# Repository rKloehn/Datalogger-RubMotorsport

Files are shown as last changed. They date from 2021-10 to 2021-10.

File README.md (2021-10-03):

# Datalogger-RubMotorsport

## Overview

For all RUB-Motorsport vehicles it makes sense to install a data logger in the vehicle. This can access and log all engine data (from the MS3) and all sensor data via the CAN bus. Up to now, RUBMotorsport has used a purchased data logger from 2D. This works well and has worked reliably over the years. However, only one data logger is available, due to the very high purchase price and the relatively easy installation in new vehicles, a new purchase was not made. The big disadvantage of this data logger is the software that comes with it. This must be used to export data from the data logger in e.g. *.csv files. The software license must be renewed every year, at the latest in February for one year. For the renewal of the license there is an annual fee of 500€. Due to the reasons mentioned above, in the 2020 season we will develop our own data logger based on a STM32F405RG. This should have all the previous functions of the 2D data logger and at a later date can also be integrated into the planned telemetry concept. 

The data logger has several connections to the outside world. These include the power supply of 12V, the connection to a GPS antenna, the possibility to process four sensor analog signals and supply them with voltage and the measurement of acceleration using an IMU. The option to store the measurement data on a microSD card is also part of the peripherals.

<p align="center">
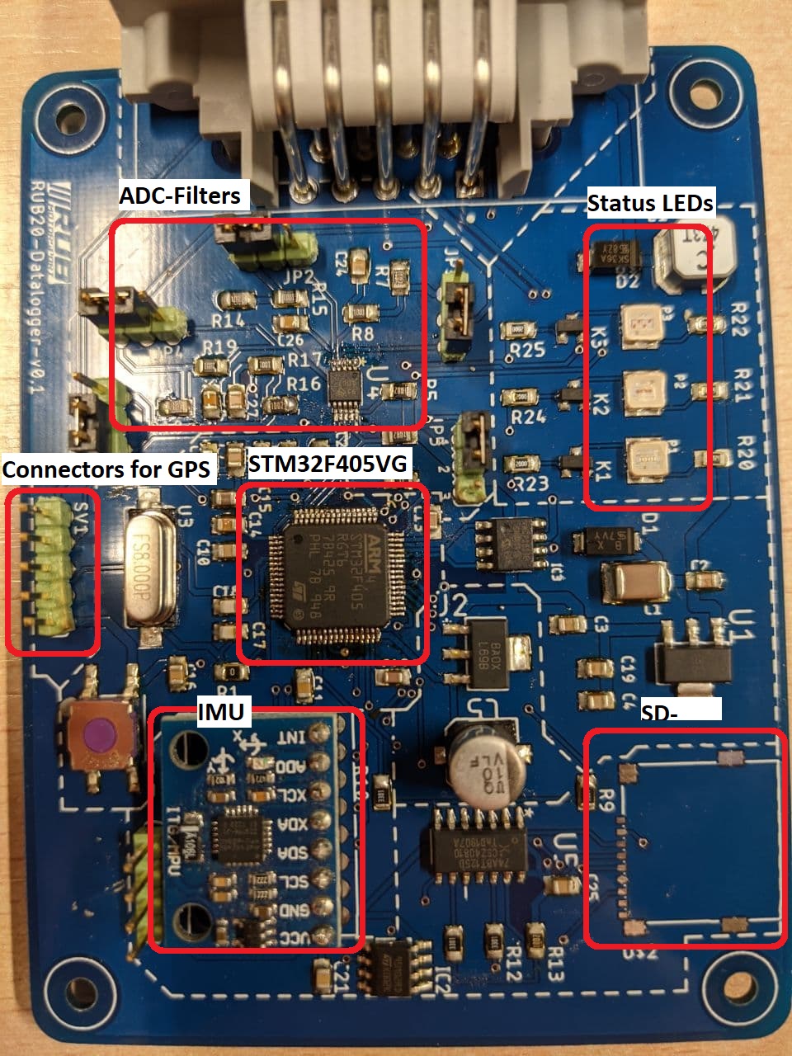
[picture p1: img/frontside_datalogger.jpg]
	
</p>

<p align="center">
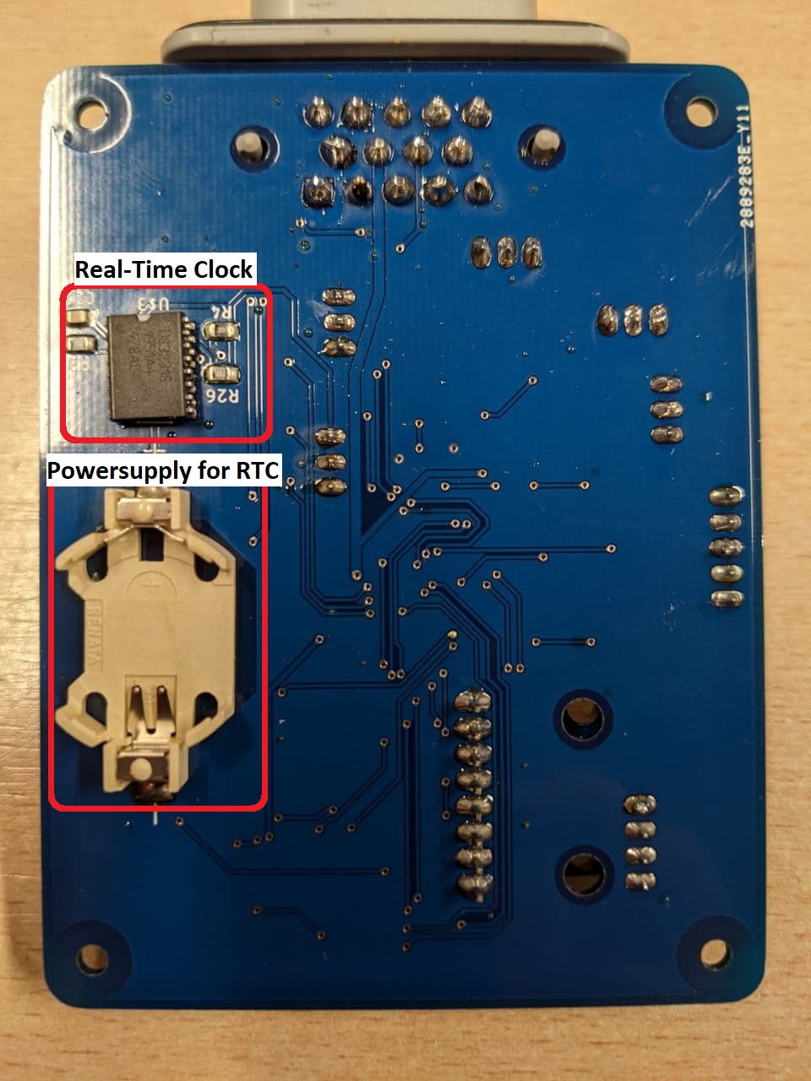
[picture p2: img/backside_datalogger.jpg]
	
</p>

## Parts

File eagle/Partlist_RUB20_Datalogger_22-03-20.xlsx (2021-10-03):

Part | Value | Package | Library | Bestellnummer
C1 | 22u | C1812K | rcl
C2 | 0.33u | C0805 | rcl
C3 | 0.1u | C0805 | rcl
C4 | 0.1u | C0805 | rcl
C5 | 10UF | CAPAE430X610N | Panasonic-EEEFK_EEEFP
C6 | 4.7u | C0805 | rcl
C7 | 0.1u | C0805 | rcl
C8 | 0.1u | C0805 | rcl
C9 | 0.1 | C0805 | rcl
C10 | 0.1 | C0805 | rcl
C11 | 0.1 | C0805 | rcl
C12 | 2.2u | C0805 | rcl
C13 | 2.2u | C0805 | rcl
C14 | 10n | C0805 | rcl
C15 | 1u | C0805 | rcl
C16 | 0.1u | C0805 | rcl
C17 | 20p | C0805 | rcl
C18 | 20p | C0805 | rcl
C19 | 0.1u | C0805 | rcl
C20 | 0.1u | C0805 | rcl
C21 | 100n | C0805 | rcl
C24 | 1n | C0805 | rcl
C25 | 100n | C0805 | rcl
C26 | 1n | C0805 | rcl
C27 | 1n | C0805 | rcl
C28 | 1n | C0805 | rcl
D1 | SMAJ22 | SMA-DO214AC | RUBM_PARTS
D2 | SK36SMA | DO214AC | RUBM_PARTS
IC1 | STM32F405RG | LQFP64 | RUBM_PARTS
IC2 | M95M02-DRMN6TP | SOIC127P600X175-8N | SamacSys_Parts
IC3 | MCP2551 | 8SO | RUBM_PARTS
JP1 | 1X03 | pinhead | (1050
JP2 | 1X03 | pinhead | (776.79995
JP3 | 1X03 | pinhead | (1405
JP4 | 1X03 | pinhead | (1050
JP5 | JP2 | jumper | (1600
K1 | IRLML62244 | SOT23-MICRO | RUBM_PARTS
K2 | IRLML62244 | SOT23-MICRO | RUBM_PARTS
K3 | IRLML62244 | SOT23-MICRO | RUBM_PARTS
L1 | LPS6235 | LPS6235 | RUBM_PARTS
P1 | XLAMP_ML-E | CREE_XLAMP_ML-E | RUBM_PARTS
P2 | XLAMP_ML-E | CREE_XLAMP_ML-E | RUBM_PARTS
P3 | XLAMP_ML-E | CREE_XLAMP_ML-E | RUBM_PARTS
R1 | 0 | R0805 | rcl
R2 | 0 | R0805 | rcl
R5 | 10k | R0805 | rcl
R6 | 10k | R0805 | rcl
R7 | 10k | R0805 | rcl
R8 | 1k | R0805 | rcl
R9 | 3.3k | R0805 | rcl
R10 | 3.3k | R0805 | rcl
R11 | 3.3k | R0805 | rcl
R12 | 3.3k | R0805 | rcl
R13 | 10k | R0805 | rcl
R14 | 10k | R0805 | rcl
R15 | 1k | R0805 | rcl
R16 | 10k | R0805 | rcl
R17 | 1k | R0805 | rcl
R18 | 10k | R0805 | rcl
R19 | 1k | R0805 | rcl
R20 | 48.7 | R0805 | rcl
R21 | 48.7 | R0805 | rcl
R22 | 48.7 | R0805 | rcl
R23 | 200 | R0805 | rcl
R24 | 200 | R0805 | rcl
R25 | 200 | R0805 | rcl
S1 | KSE-M-31-G | KSE-M-31-G | RUBM_PARTS
SV1 | 1X05 | pinhead | (1950
SV2 | 1X04 | pinhead | (3100
U$1 | 776267-4 | TE_776267-4 | 776267-4
U$2 | MICROSD-PUSH-OUT | MICROSD-PUSH-OUT | microsd
U1 | UA78M05CDCY | SOT230P700X180-4N | RUBM_PARTS
U2 | LM2937IMP-3.3/NOPB | SOT230P700X180-4N | RUBM_PARTS
U3 | FOX_SDLF | HC49SSDLF | RUBM_PARTS
U4 | ADS1115IDGST | SOP50P490X110-10N | Texas |  | R0
U5 | 74ABT125D | SOIC127P600X175-14N | NXP_By_element14_Batch_1
U6 | GY-521MPU6050 | GY-521 | gy-521_holes

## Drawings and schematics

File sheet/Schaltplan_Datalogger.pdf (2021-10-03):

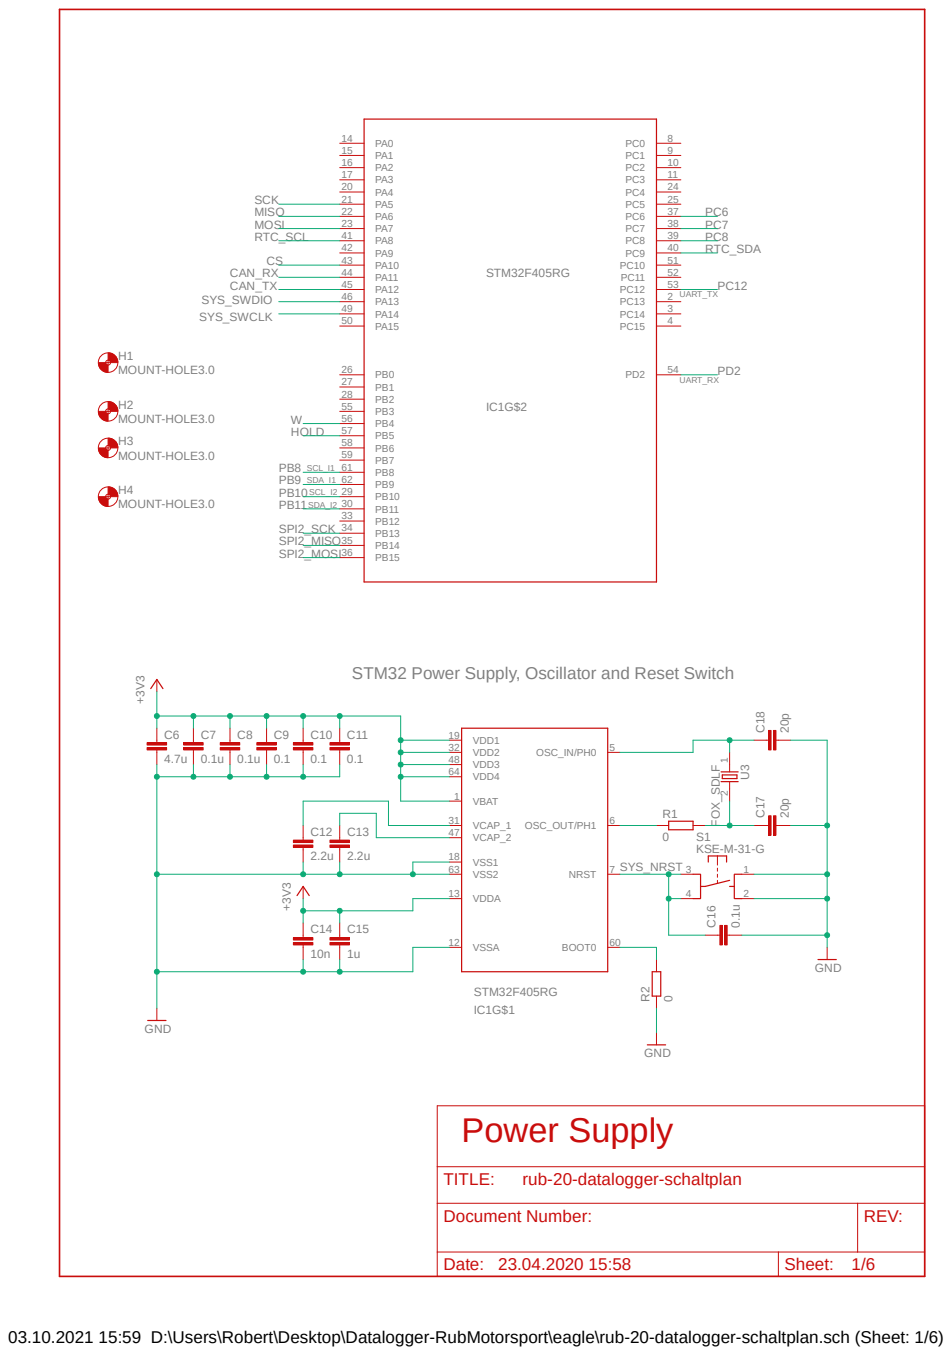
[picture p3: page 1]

STM32 Power Supply, Oscillator and Reset Switch

Document Number: | REV:

Date: 23.04.2020 15:58 | Sheet: 1/6

03.10.2021 15:59 D:\Users\Robert\Desktop\Datalogger-RubMotorsport\eagle\rub-20-datalogger-schaltplan.sch (Sheet: 1/6)

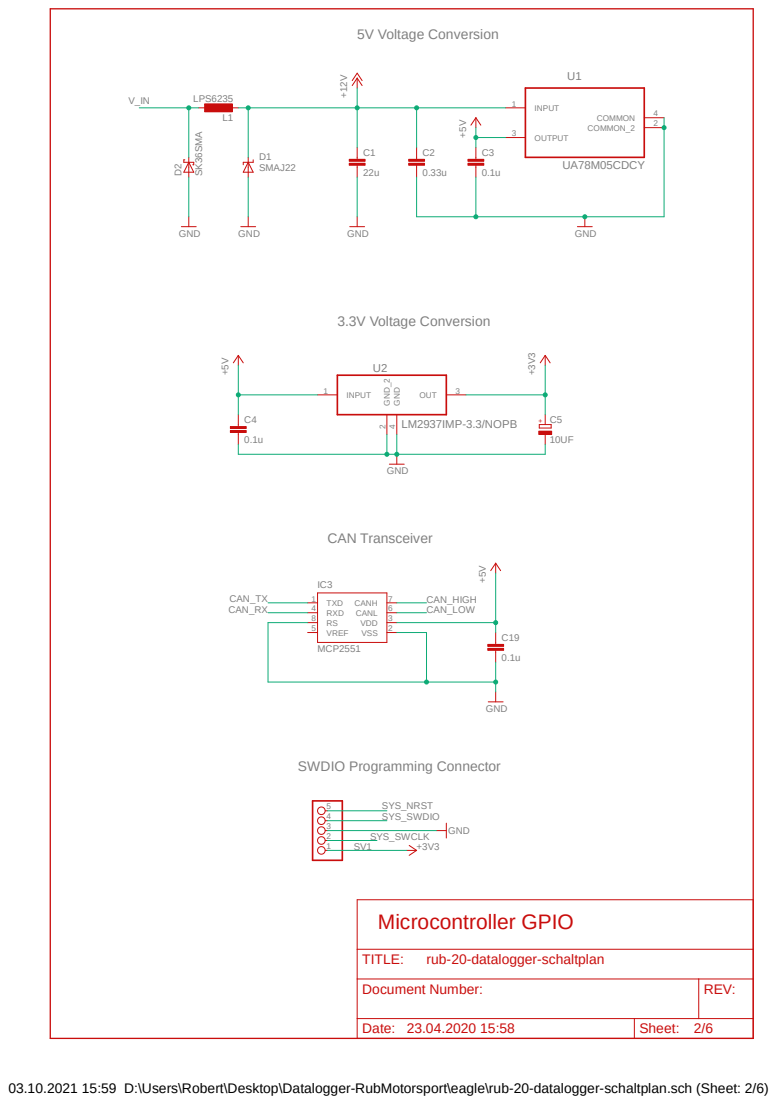
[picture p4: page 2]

Document Number: | REV:

03.10.2021 15:59 D:\Users\Robert\Desktop\Datalogger-RubMotorsport\eagle\rub-20-datalogger-schaltplan.sch (Sheet: 2/6)

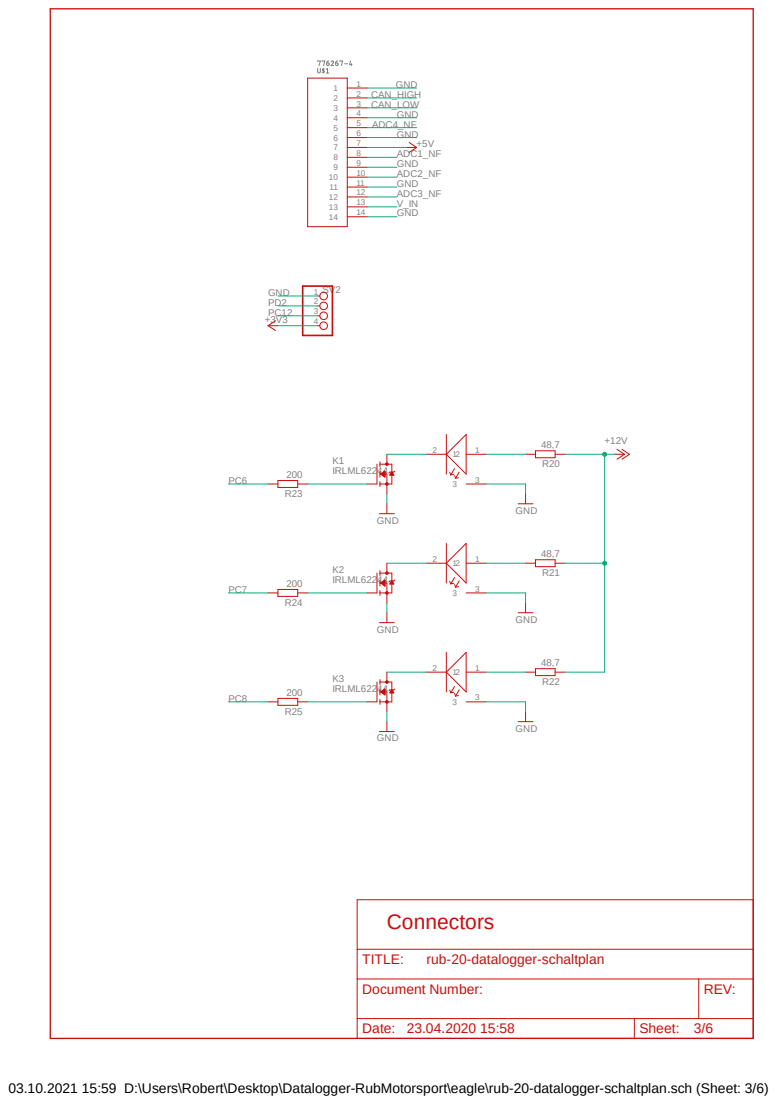
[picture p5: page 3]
GND; IRLML62244; CAN_HIGH CAN_LOW; ADC1_NF; ADC2_NF; ADC3_NF; ADC4_NF; Connectors; TITLE:

rub-20-datalogger-schaltplan

Document Number: | REV:

03.10.2021 15:59 D:\Users\Robert\Desktop\Datalogger-RubMotorsport\eagle\rub-20-datalogger-schaltplan.sch (Sheet: 3/6)

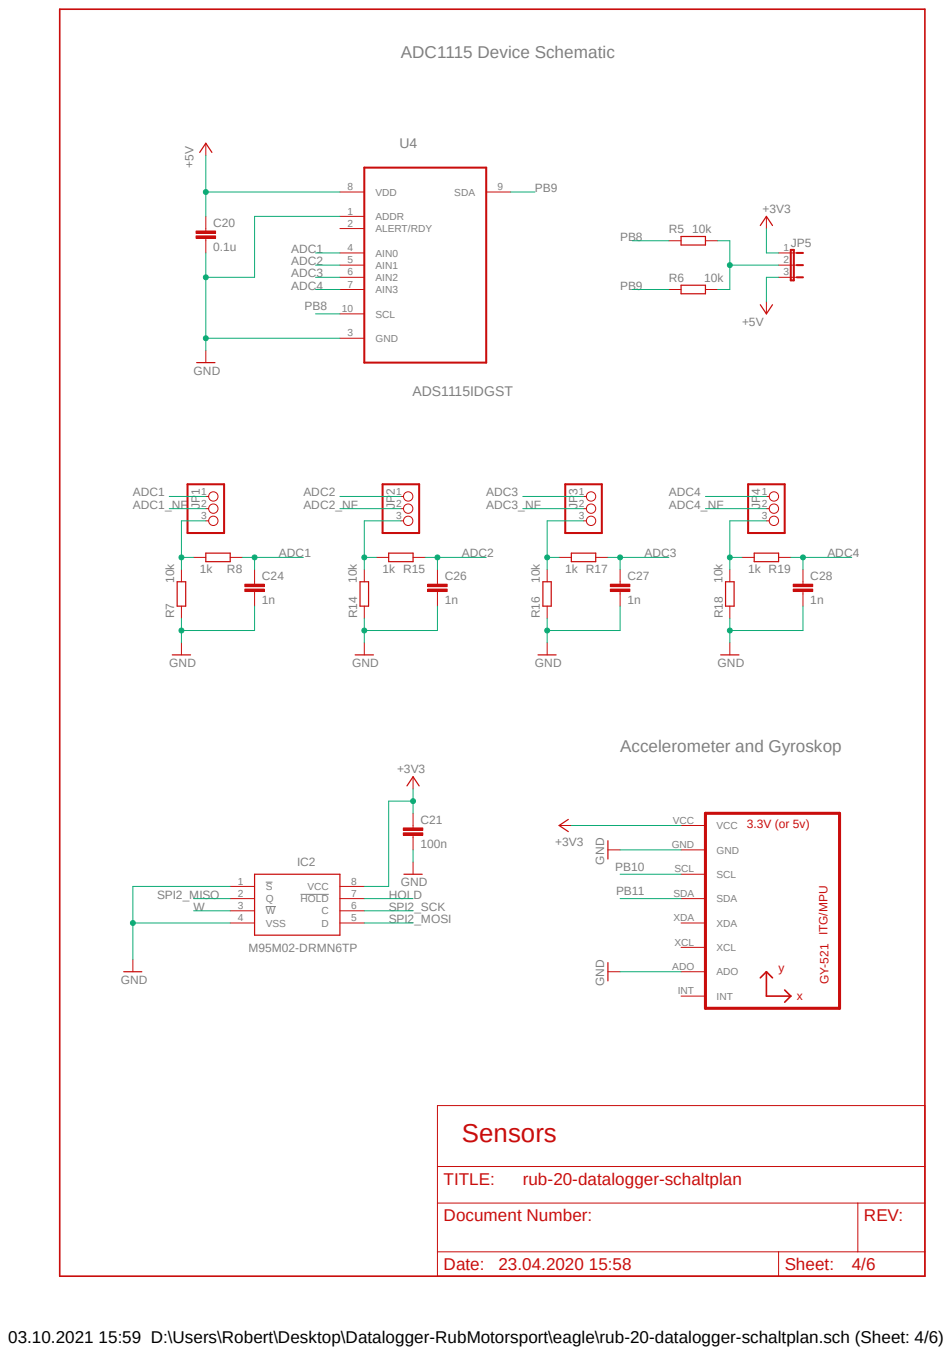
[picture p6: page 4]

Document Number: | REV:

03.10.2021 15:59 D:\Users\Robert\Desktop\Datalogger-RubMotorsport\eagle\rub-20-datalogger-schaltplan.sch (Sheet: 4/6)

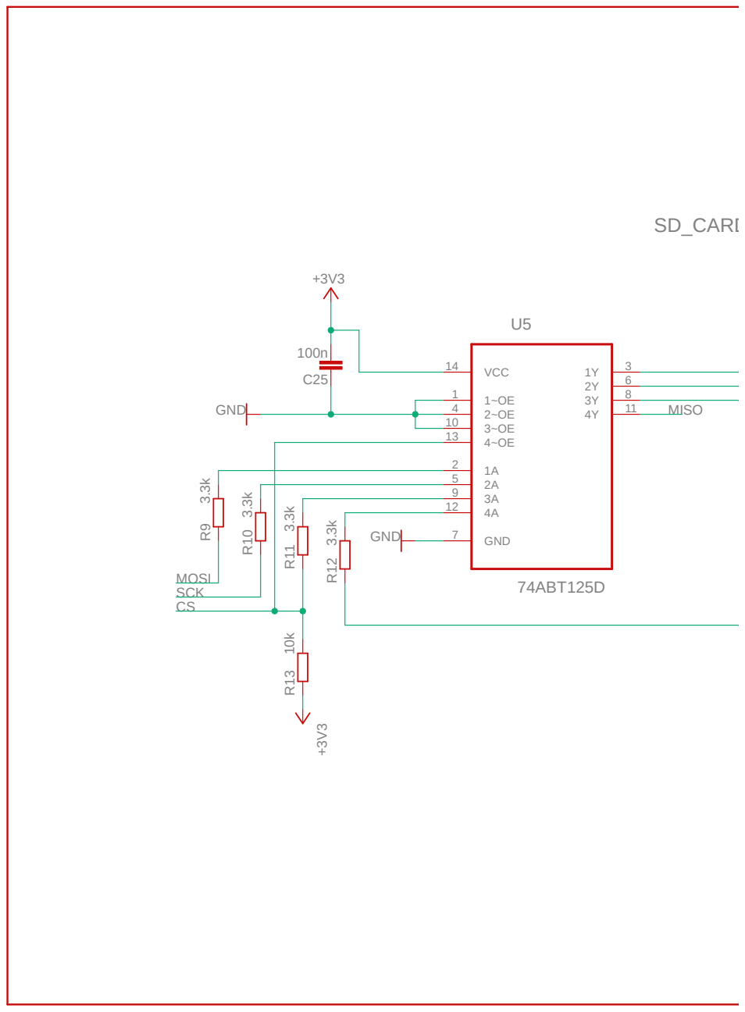
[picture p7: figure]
SD_CARD with SPI; 74ABT125D; GND 3.3k; GND; VCC 14; GND 7; R¹⁰; R¹¹; R¹² R¹³; MISO; MOSI SCK CS

03.10.2021 15:59 D:\Users\Robert\Desktop\Datalogger-RubMotorsport\eagle\rub-20-datalogger-schaltplan.sch (Sheet: 5/6)

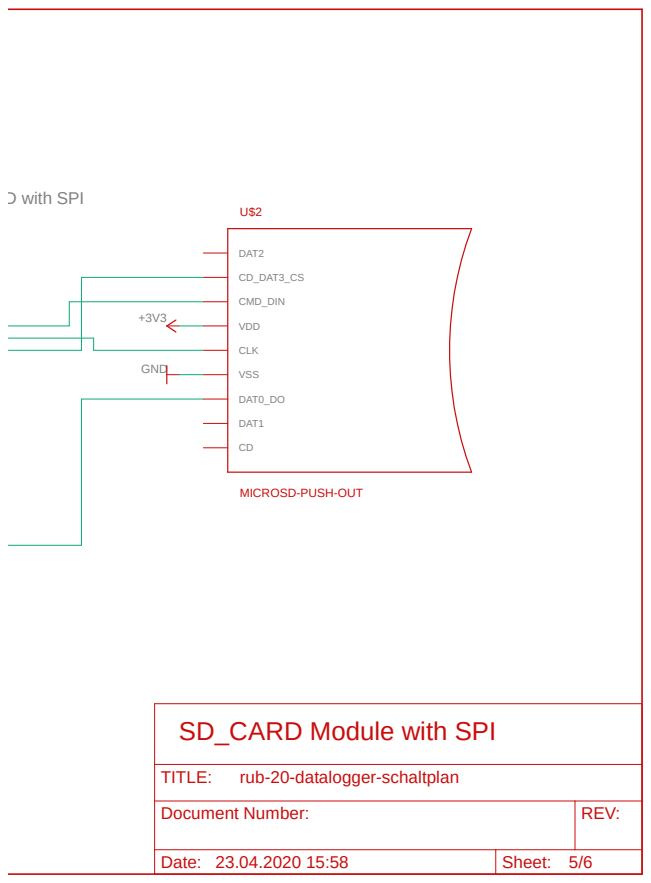
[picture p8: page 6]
GND; DAT2; CD_DAT3_CS; CMD_DIN; VSS; VDD; CLK; DAT0_DO; DAT1; Date:; Sheet:; REV:; TITLE:; Document Number:

MICROSD-PUSH-OUT

SD_CARD Module with SPI

rub-20-datalogger-schaltplan

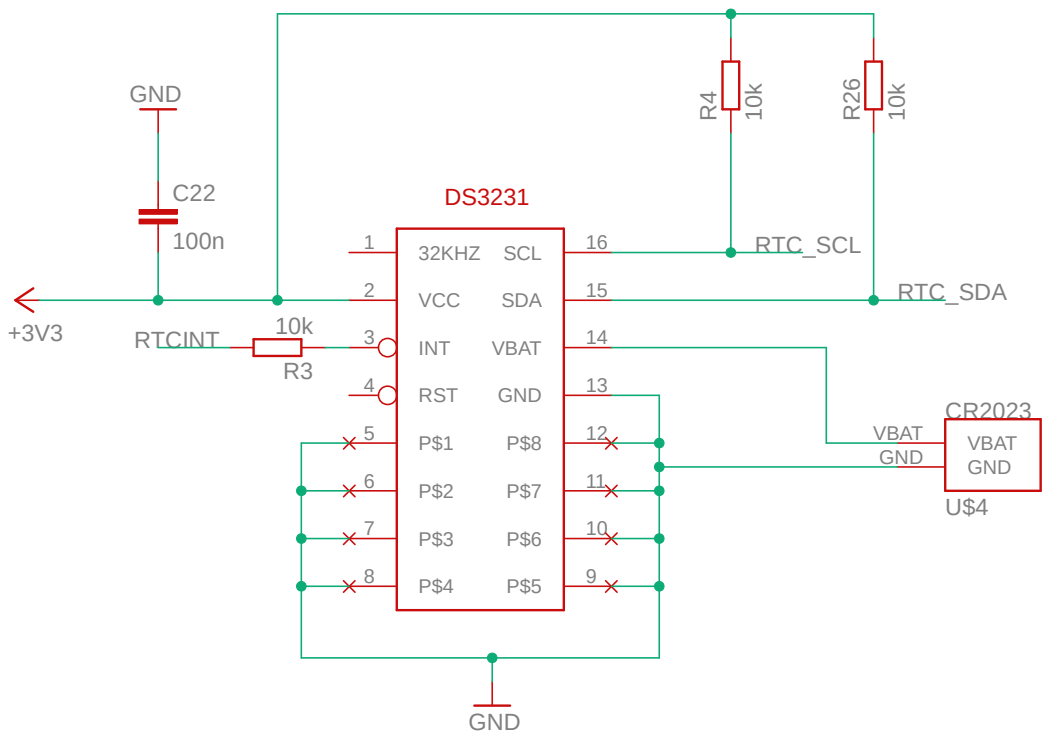
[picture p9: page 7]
GND; SCL; SDA; VBAT; INT 3; RST 4; 32KHZ 1; VCC 2; R²⁶; VBAT VBAT GND GND U$4; RTC_SDA; RTCINT; RTC_SCL; TITLE:

rub-20-datalogger-schaltplan

Document Number: | REV:

03.10.2021 15:59 D:\Users\Robert\Desktop\Datalogger-RubMotorsport\eagle\rub-20-datalogger-schaltplan.sch (Sheet: 6/6)

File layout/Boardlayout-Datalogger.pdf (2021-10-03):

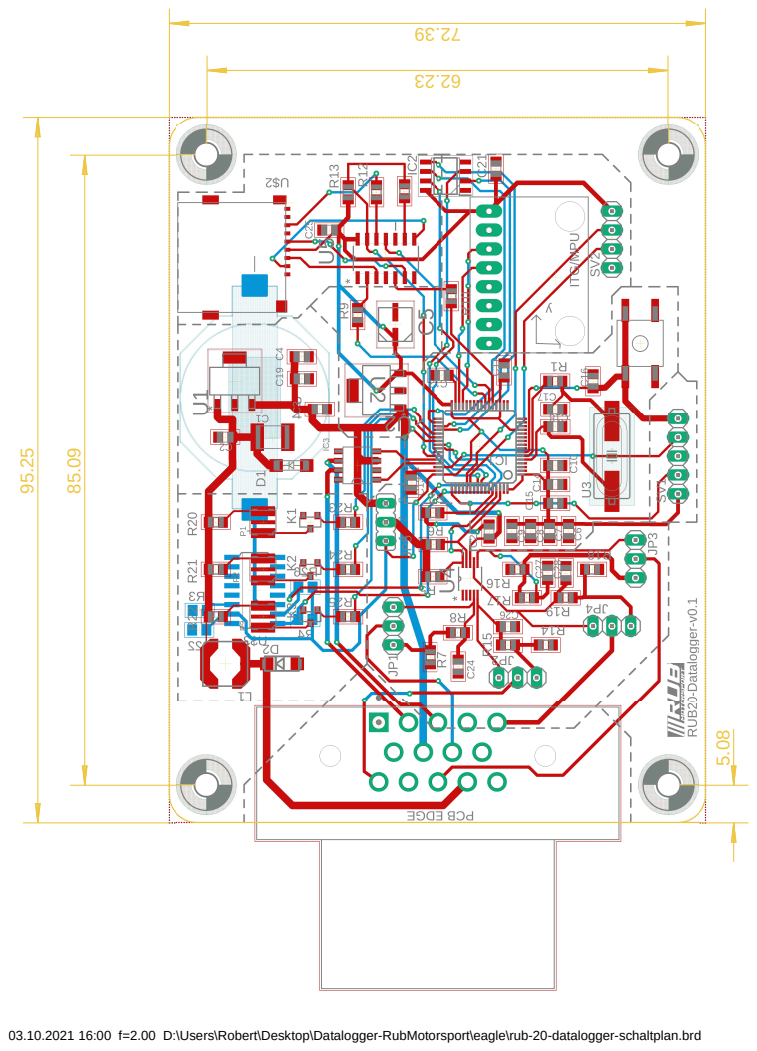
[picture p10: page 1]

03.10.2021 16:00 f=2.00 D:\Users\Robert\Desktop\Datalogger-RubMotorsport\eagle\rub-20-datalogger-schaltplan.brd ⁹⁵.25

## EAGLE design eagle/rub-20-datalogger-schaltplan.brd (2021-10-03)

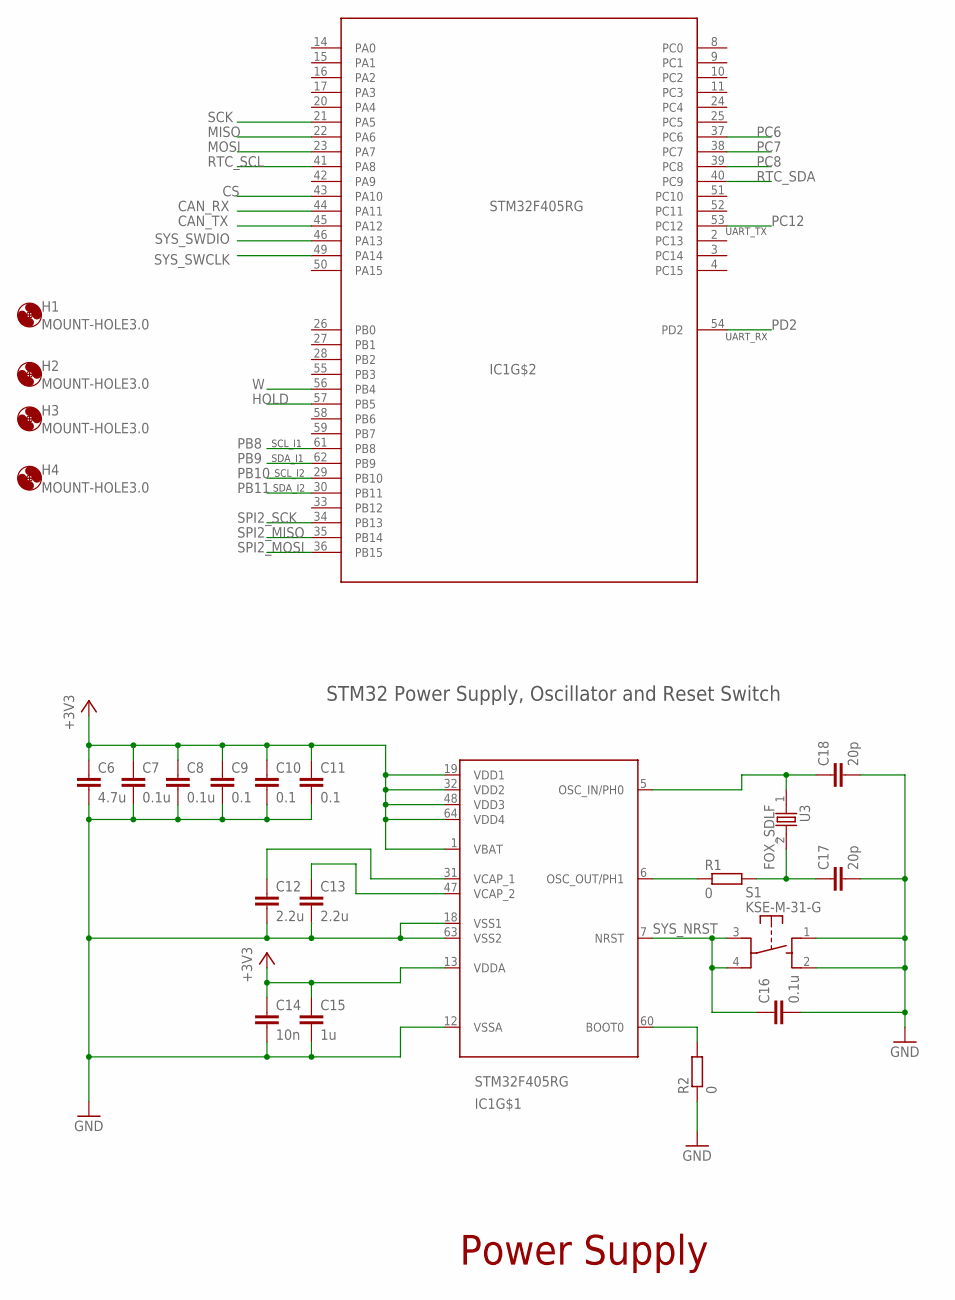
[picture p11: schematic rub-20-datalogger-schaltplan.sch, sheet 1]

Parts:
C6: 4.7u; C0805
C7, C8, C16: 0.1u; C0805
C9, C10, C11: 0.1; C0805
C12, C13: 2.2u; C0805
C14: 10n; C0805
C15: 1u; C0805
C17, C18: 20p; C0805
H1, H2, H3, H4: MOUNT-HOLE3.0; 3,0
IC1: STM32F405RG; LQFP64
R1, R2: 0; R0805
S1: KSE-M-31-G
U3: FOX_SDLF; HC49SSDLF

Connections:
+3V3: C6.1, C7.1, C8.1, C9.1, C10.1, C11.1, C14.1, C15.1, IC1.1 (VBAT), IC1.13 (VDDA), IC1.19 (VDD1), IC1.32 (VDD2), IC1.48 (VDD3), IC1.64 (VDD4); also elsewhere on the board
CAN_RX: IC1.44 (PA11); also elsewhere on the board
CAN_TX: IC1.45 (PA12); also elsewhere on the board
CS: IC1.43 (PA10); also elsewhere on the board
GND: C6.2, C7.2, C8.2, C9.2, C10.2, C11.2, C12.2, C13.2, C14.2, C15.2, C16.2, C17.2, C18.2, IC1.12 (VSSA), IC1.18 (VSS1), IC1.63 (VSS2), R2.1, S1.1, S1.2; also elsewhere on the board
HOLD: IC1.57 (PB5); also elsewhere on the board
MISO: IC1.22 (PA6); also elsewhere on the board
MOSI: IC1.23 (PA7); also elsewhere on the board
unnamed: C13.1, IC1.47 (VCAP_2)
unnamed: C12.1, IC1.31 (VCAP_1)
unnamed: IC1.60 (BOOT0), R2.2
unnamed: IC1.6 (OSC_OUT/PH1), R1.1
unnamed: C17.1, R1.2, U3.2
unnamed: C18.1, IC1.5 (OSC_IN/PH0), U3.1
PB8: IC1.61 (PB8); also elsewhere on the board
PB9: IC1.62 (PB9); also elsewhere on the board
PB10: IC1.29 (PB10); also elsewhere on the board
PB11: IC1.30 (PB11); also elsewhere on the board
PC6: IC1.37 (PC6); also elsewhere on the board
PC7: IC1.38 (PC7); also elsewhere on the board
PC8: IC1.39 (PC8); also elsewhere on the board
PC12: IC1.53 (PC12); also elsewhere on the board
PD2: IC1.54 (PD2); also elsewhere on the board
RTC_SCL: IC1.41 (PA8); also elsewhere on the board
RTC_SDA: IC1.40 (PC9); also elsewhere on the board
SCK: IC1.21 (PA5); also elsewhere on the board
SPI2_MISO: IC1.35 (PB14); also elsewhere on the board
SPI2_MOSI: IC1.36 (PB15); also elsewhere on the board
SPI2_SCK: IC1.34 (PB13); also elsewhere on the board
SYS_NRST: C16.1, IC1.7 (NRST), S1.3, S1.4; also elsewhere on the board
SYS_SWCLK: IC1.49 (PA14); also elsewhere on the board
SYS_SWDIO: IC1.46 (PA13); also elsewhere on the board
W: IC1.56 (PB4); also elsewhere on the board

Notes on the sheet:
Power Supply
STM32 Power Supply, Oscillator and Reset Switch
SCL_I1
SDA_I1
UART_RX
UART_TX
SCL_I2
SDA_I2

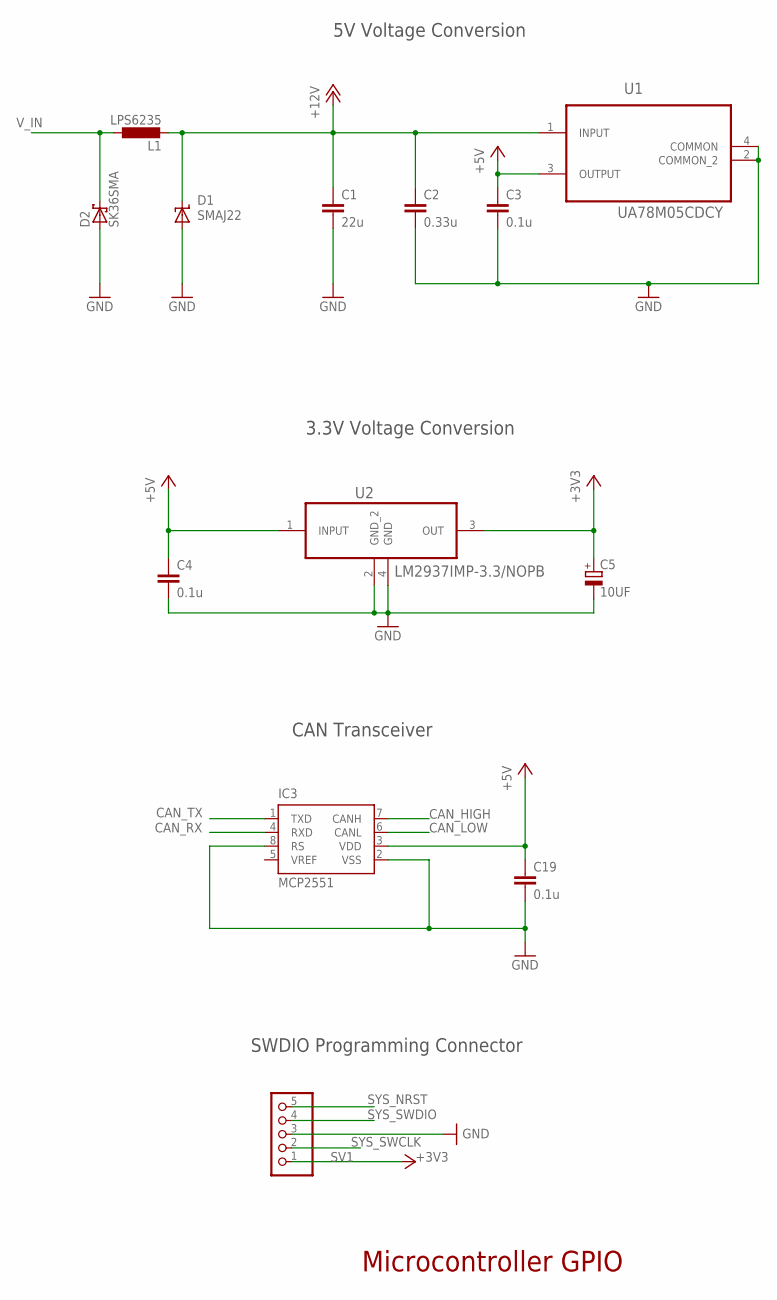
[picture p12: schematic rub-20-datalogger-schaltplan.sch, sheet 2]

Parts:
C1: 22u; C1812K
C2: 0.33u; C0805
C3, C4, C19: 0.1u; C0805
C5: 10UF; CAPAE430X610N
D1: SMAJ22; SMA-DO214AC
D2: SK36SMA; DO214AC
IC3: MCP2551; 8SO
L1: LPS6235
SV1: PINHD-1X5; 1X05
U1: UA78M05CDCY; SOT230P700X180-4N
U2: LM2937IMP-3.3/NOPB; SOT230P700X180-4N

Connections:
+3V3: C5.1 (+), SV1.1, U2.3 (OUT); also elsewhere on the board
+5V: C3.1, C4.1, C19.1, IC3.3 (VDD), U1.3 (OUTPUT), U2.1 (INPUT); also elsewhere on the board
+12V: C1.1, C2.1, D1.K (C), L1.2, U1.1 (INPUT); also elsewhere on the board
CAN_HIGH: IC3.7 (CANH); also elsewhere on the board
CAN_LOW: IC3.6 (CANL); also elsewhere on the board
CAN_RX: IC3.4 (RXD); also elsewhere on the board
CAN_TX: IC3.1 (TXD); also elsewhere on the board
GND: C1.2, C2.2, C3.2, C4.2, C5.2 (-), C19.2, D1.A, D2.A, IC3.2 (VSS), IC3.8 (RS), SV1.3, U1.2 (COMMON_2), U1.4 (COMMON), U2.2 (GND_2), U2.4 (GND); also elsewhere on the board
SYS_NRST: SV1.5; also elsewhere on the board
SYS_SWCLK: SV1.2; also elsewhere on the board
SYS_SWDIO: SV1.4; also elsewhere on the board
V_IN: D2.C, L1.1; also elsewhere on the board

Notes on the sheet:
CAN Transceiver
Microcontroller GPIO
SWDIO Programming Connector
3.3V Voltage Conversion
5V Voltage Conversion

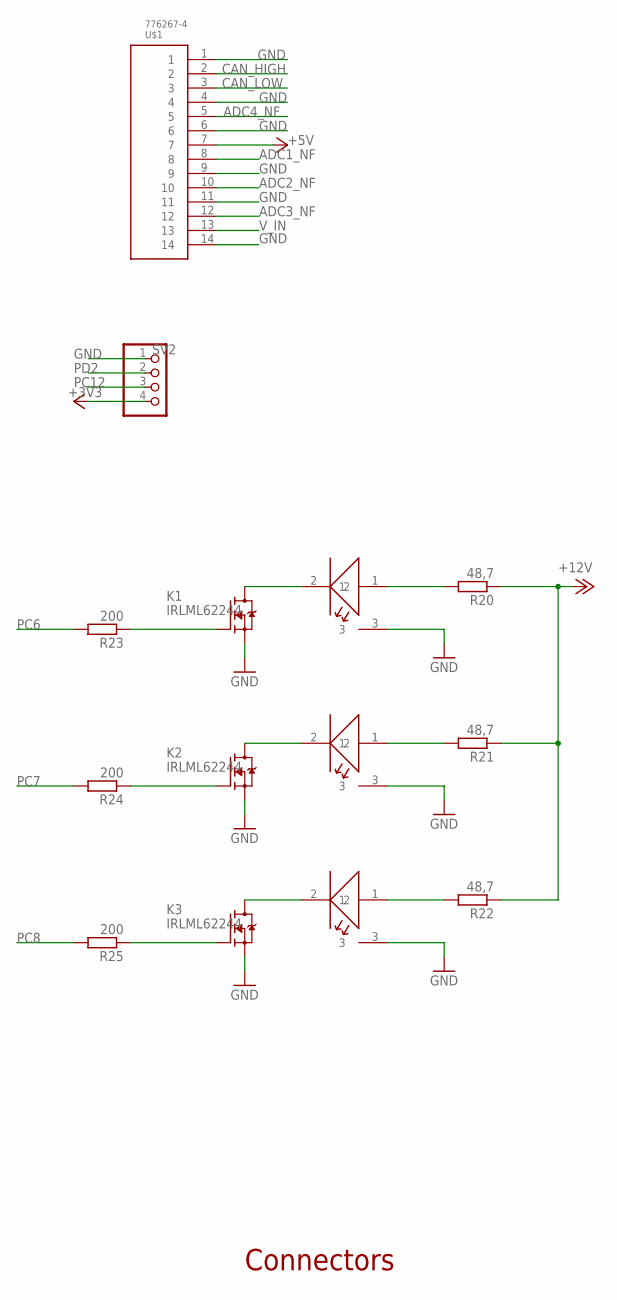
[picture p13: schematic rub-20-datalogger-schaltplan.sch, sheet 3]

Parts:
K1, K2, K3: IRLML62244; SOT23-MICRO
P1, P2, P3: XLAMP_ML-E; CREE_XLAMP_ML-E
R20, R21, R22: 48,7; R0805
R23, R24, R25: 200; R0805
SV2: PINHD-1X4; 1X04
U$1: 776267-4; TE_776267-4

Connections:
+3V3: SV2.4; also elsewhere on the board
+5V: U$1.7; also elsewhere on the board
+12V: R20.1, R21.1, R22.1; also elsewhere on the board
ADC1_NF: U$1.8; also elsewhere on the board
ADC2_NF: U$1.10; also elsewhere on the board
ADC3_NF: U$1.12; also elsewhere on the board
ADC4_NF: U$1.5; also elsewhere on the board
CAN_HIGH: U$1.2; also elsewhere on the board
CAN_LOW: U$1.3; also elsewhere on the board
GND: K1.2 (S), K2.2 (S), K3.2 (S), P1.3, P2.3, P3.3, SV2.1, U$1.1, U$1.4, U$1.6, U$1.9, U$1.11, U$1.14; also elsewhere on the board
unnamed: P2.1, R21.2
unnamed: P1.1, R20.2
unnamed: P3.1, R22.2
unnamed: K1.1 (G), R23.1
unnamed: K2.1 (G), R24.1
unnamed: K3.1 (G), R25.1
unnamed: K1.3 (D), P1.2
unnamed: K2.3 (D), P2.2
unnamed: K3.3 (D), P3.2
PC6: R23.2; also elsewhere on the board
PC7: R24.2; also elsewhere on the board
PC8: R25.2; also elsewhere on the board
PC12: SV2.3; also elsewhere on the board
PD2: SV2.2; also elsewhere on the board
V_IN: U$1.13; also elsewhere on the board

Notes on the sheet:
Connectors

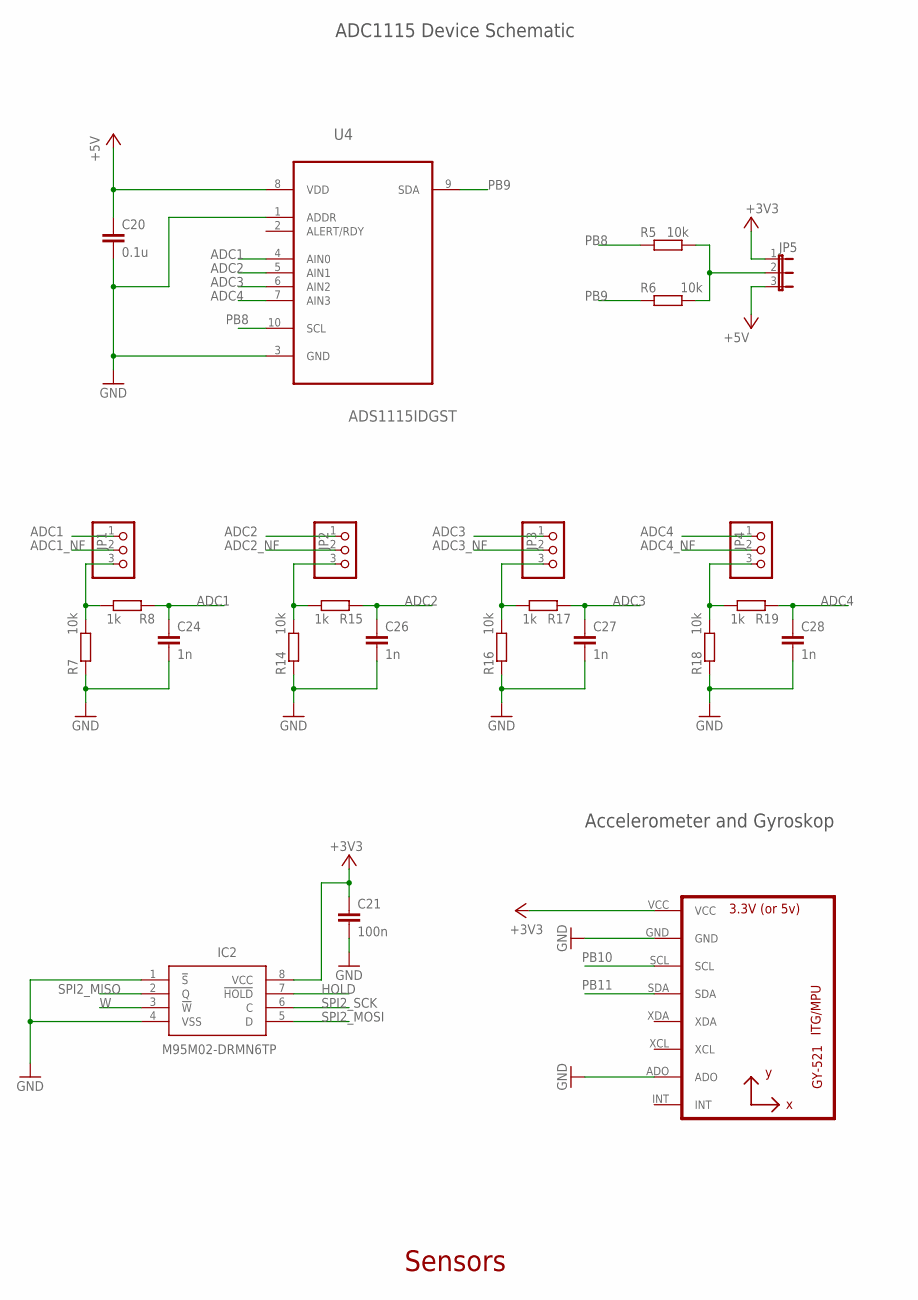
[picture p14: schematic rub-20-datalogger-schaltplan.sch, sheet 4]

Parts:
C20: 0.1u; C0805
C21: 100n; C0805
C24, C26, C27, C28: 1n; C0805
IC2: M95M02-DRMN6TP; SOIC127P600X175-8N
JP1, JP2, JP3, JP4: PINHD-1X3; 1X03
JP5: JP2E; JP2
R5, R6, R7, R14, R16, R18: 10k; R0805
R8, R15, R17, R19: 1k; R0805
U4: ADS1115IDGST; SOP50P490X110-10N
U6: GY-521MPU6050; GY-521

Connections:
+3V3: C21.1, IC2.8 (VCC), JP5.1, U6.VCC; also elsewhere on the board
+5V: C20.1, JP5.3, U4.8 (VDD); also elsewhere on the board
ADC1: C24.1, JP1.1, R8.2, U4.4 (AIN0)
ADC1_NF: JP1.2; also elsewhere on the board
ADC2: C26.1, JP2.1, R15.2, U4.5 (AIN1)
ADC2_NF: JP2.2; also elsewhere on the board
ADC3: C27.1, JP3.1, R17.2, U4.6 (AIN2)
ADC3_NF: JP3.2; also elsewhere on the board
ADC4: C28.1, JP4.1, R19.2, U4.7 (AIN3)
ADC4_NF: JP4.2; also elsewhere on the board
GND: C20.2, C21.2, C24.2, C26.2, C27.2, C28.2, IC2.1 (!S), IC2.4 (VSS), R7.2, R14.2, R16.2, R18.2, U4.1 (ADDR), U4.3 (GND), U6.ADO, U6.GND; also elsewhere on the board
HOLD: IC2.7 (!HOLD); also elsewhere on the board
unnamed: JP1.3, R7.1, R8.1
unnamed: JP2.3, R14.1, R15.1
unnamed: JP3.3, R16.1, R17.1
unnamed: JP4.3, R18.1, R19.1
unnamed: JP5.2, R5.1, R6.1
PB8: R5.2, U4.10 (SCL); also elsewhere on the board
PB9: R6.2, U4.9 (SDA); also elsewhere on the board
PB10: U6.SCL; also elsewhere on the board
PB11: U6.SDA; also elsewhere on the board
SPI2_MISO: IC2.2 (Q); also elsewhere on the board
SPI2_MOSI: IC2.5 (D); also elsewhere on the board
SPI2_SCK: IC2.6 (C); also elsewhere on the board
W: IC2.3 (!W); also elsewhere on the board

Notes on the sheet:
ADC1115 Device Schematic
Accelerometer and Gyroskop
Sensors

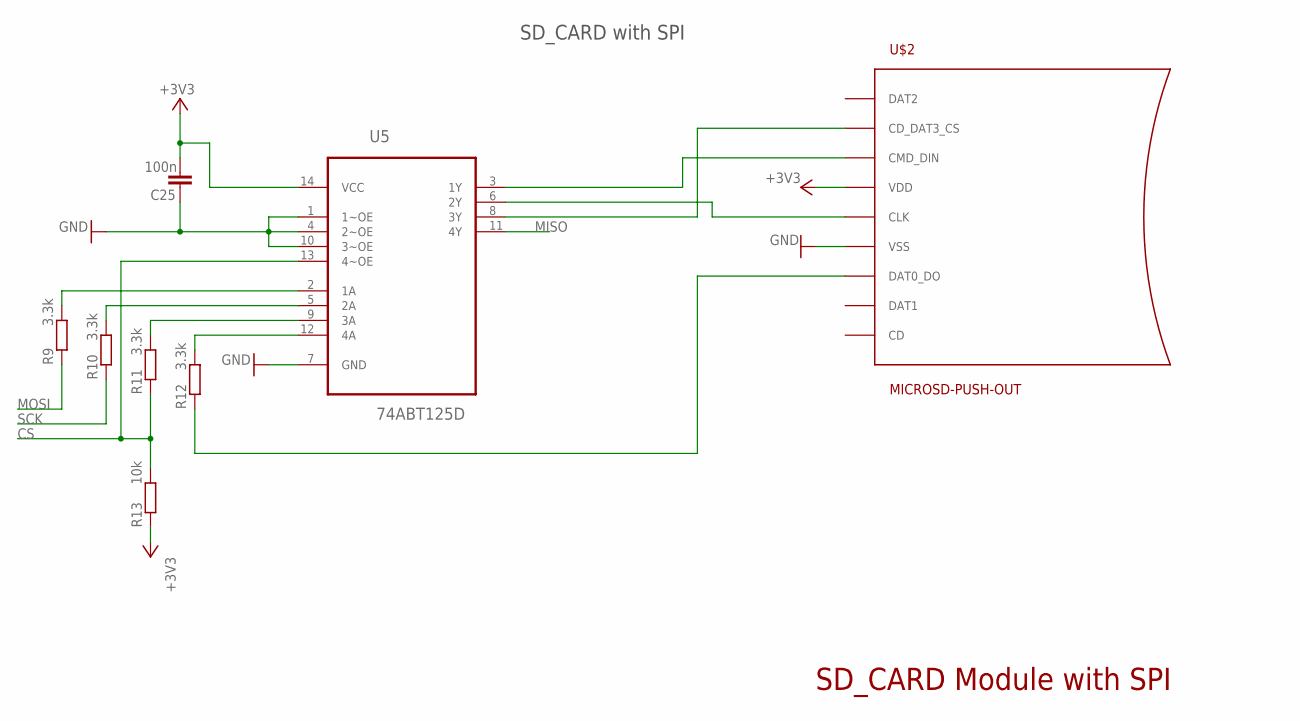
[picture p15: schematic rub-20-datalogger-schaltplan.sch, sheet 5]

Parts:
C25: 100n; C0805
R9, R10, R11, R12: 3.3k; R0805
R13: 10k; R0805
U5: 74ABT125D; SOIC127P600X175-14N
U$2: MICROSD-PUSH-OUT

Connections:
+3V3: C25.2, R13.2, U5.14 (VCC), U$2.4 (VDD); also elsewhere on the board
CS: R11.2, R13.1, U5.13 (4~OE); also elsewhere on the board
GND: C25.1, U5.1 (1~OE), U5.4 (2~OE), U5.7 (GND), U5.10 (3~OE), U$2.6 (VSS), U$2.G1 (VSS), U$2.G2 (VSS), U$2.G3 (VSS), U$2.G4 (VSS); also elsewhere on the board
MISO: U5.11 (4Y); also elsewhere on the board
MOSI: R9.2; also elsewhere on the board
unnamed: R9.1, U5.2 (1A)
unnamed: U5.8 (3Y), U$2.2 (CD_DAT3_CS)
unnamed: U5.3 (1Y), U$2.3 (CMD_DIN)
unnamed: U5.6 (2Y), U$2.5 (CLK)
unnamed: R12.1, U5.12 (4A)
unnamed: R10.1, U5.5 (2A)
unnamed: R11.1, U5.9 (3A)
unnamed: R12.2, U$2.7 (DAT0_DO)
SCK: R10.2; also elsewhere on the board

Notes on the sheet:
SD_CARD Module with SPI
SD_CARD with SPI

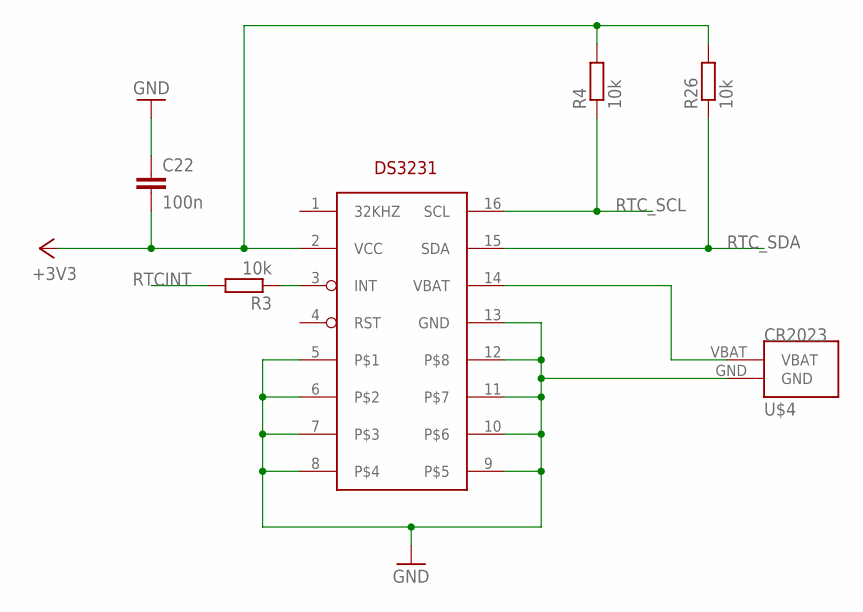
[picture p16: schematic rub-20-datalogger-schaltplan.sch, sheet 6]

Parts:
C22: 100n; C0805
R3, R4, R26: 10k; R0805
U$3: DS3231; SO16
U$4: CR2023; STMU2023-G

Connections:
+3V3: C22.2, R4.2, R26.2, U$3.2 (VCC); also elsewhere on the board
GND: C22.1, U$3.5, U$3.6, U$3.7, U$3.8, U$3.9, U$3.10, U$3.11, U$3.12, U$3.13 (GND), U$4.GND; also elsewhere on the board
unnamed: U$3.14 (VBAT), U$4.VBAT
unnamed: R3.1, U$3.3 (INT)
RTCINT: R3.2
RTC_SCL: R4.1, U$3.16 (SCL); also elsewhere on the board
RTC_SDA: R26.1, U$3.15 (SDA); also elsewhere on the board

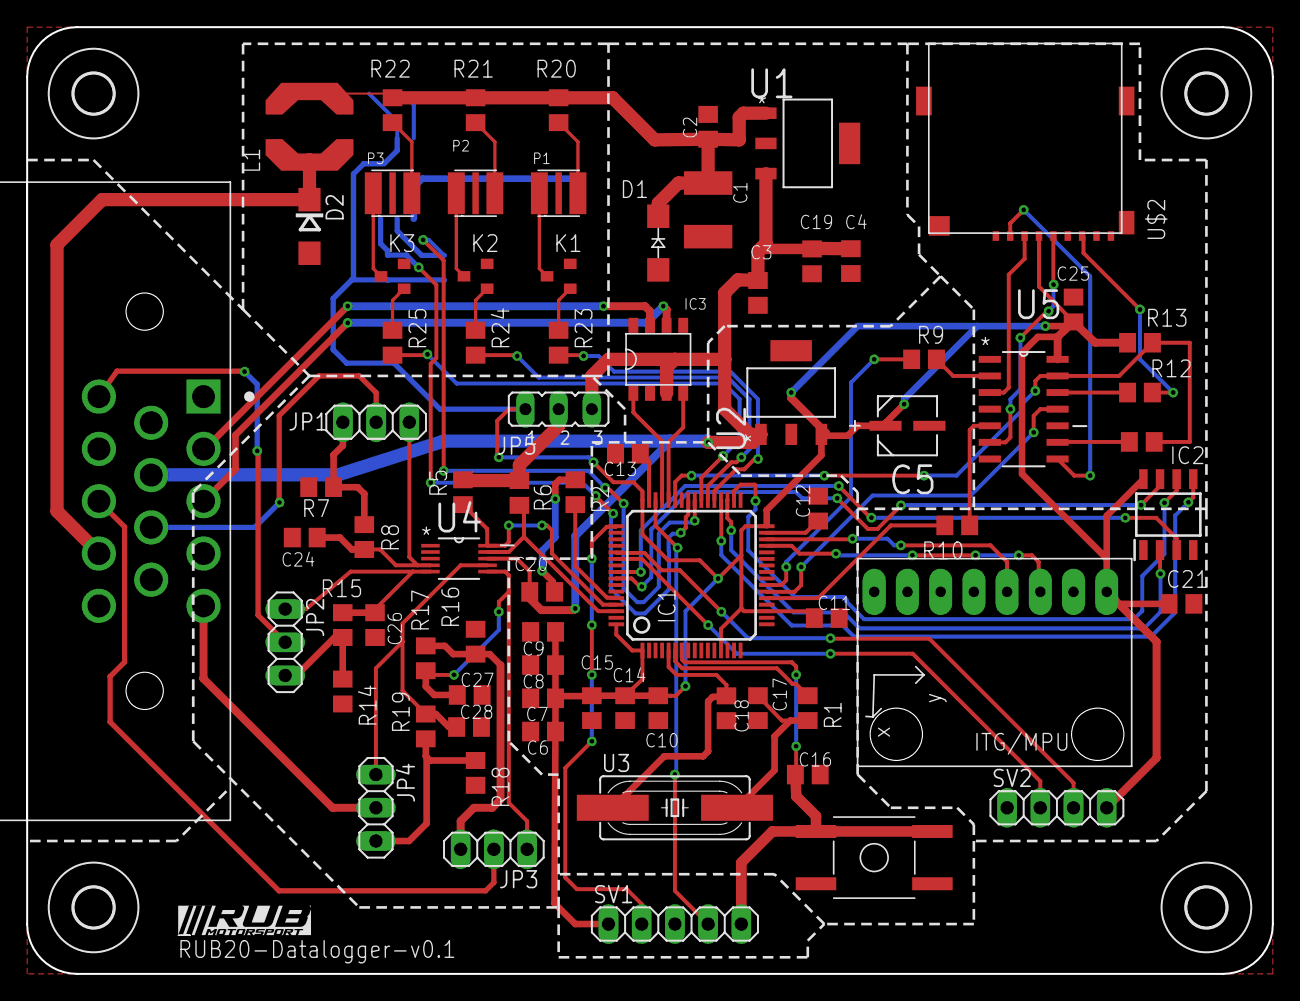
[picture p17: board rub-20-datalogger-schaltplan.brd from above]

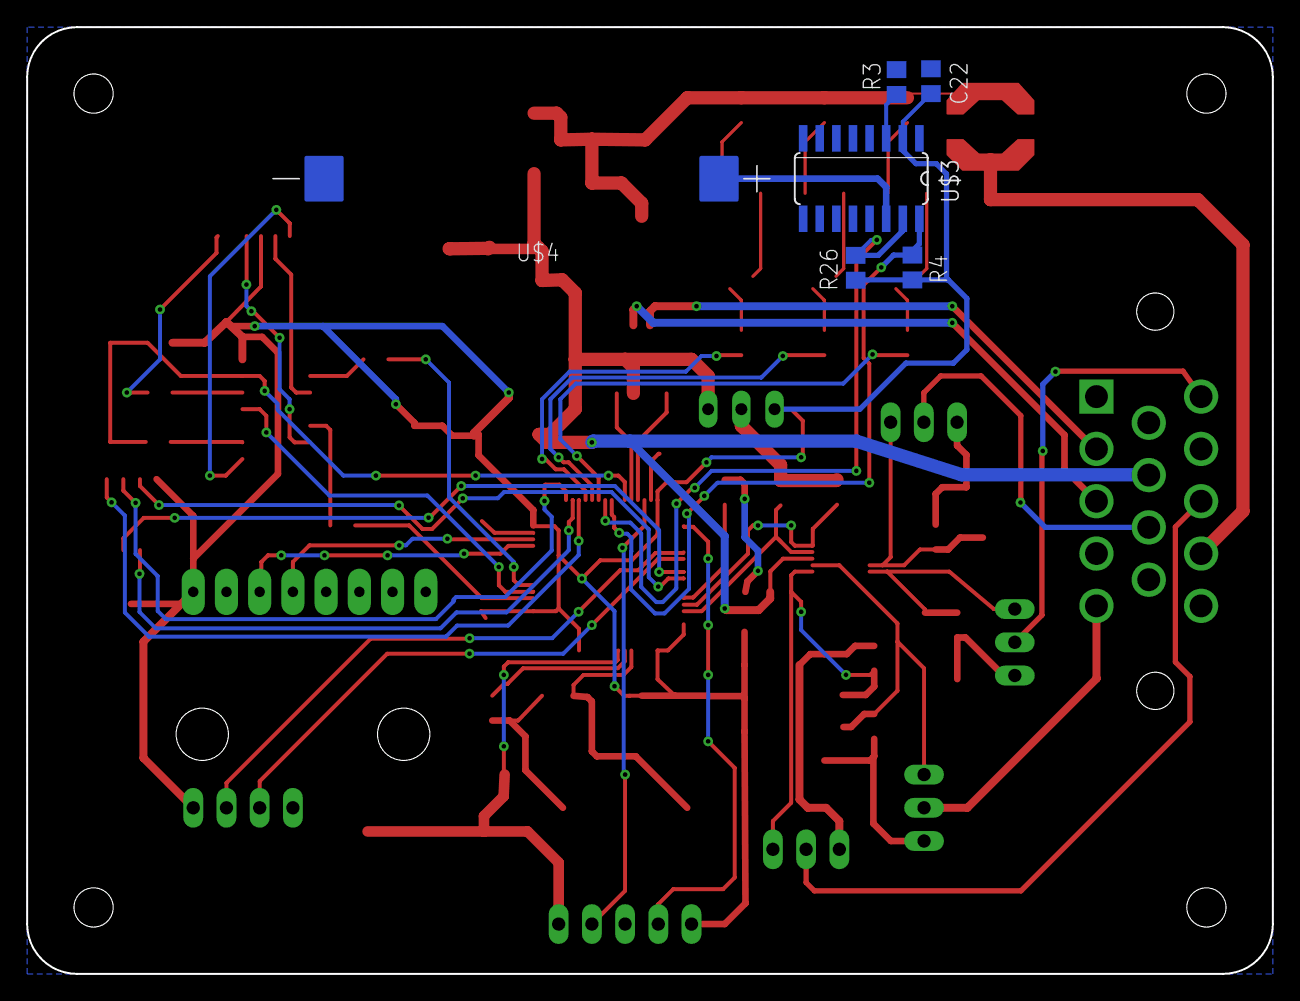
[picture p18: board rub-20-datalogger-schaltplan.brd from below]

Board: 2 copper layers, 95.2 x 72.4 mm, 87 parts (6 on the bottom side), 70 nets.
